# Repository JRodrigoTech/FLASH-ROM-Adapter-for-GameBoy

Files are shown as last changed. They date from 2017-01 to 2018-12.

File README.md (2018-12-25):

# SOP-32L FLASH to ROM Adapter for Game Boy Cartridges

Game-Boy-SOP-32-Flash-to-ROM-adapter-preview

---

# TSOP-44L FLASH to ROM Adapter

Game-Boy-TSOP-44-Flash-to-ROM-adapter-preview

#### NOTE : This adaptar this pretty hard to solder. If you are new in soldering, I recommend to use the SOP32 adapter because is much more easy to solder and fix.

---

## Compatible Flashes

AM29F016@-#E* (2 MB) or AM29F032@-#E* (4 MB)
```
 @ = Manufactured process technology (None = 0.5 µm, B = 0.32 µm, D = 0.23 µm)
 # = any speeds are compatible (75,90,120,150)
 E = 48-Pin Thin Small Outline Package (TSOP) Standard Pinout (TS 048)
 * = any temperature range (C = Commercial (0°C to +70°C) or I = Industrial (-40°C to +85°C))
```
*Ex: AM29F016-75EC, AM29F032B-120EI,...* 

---

## [How To - Assembly Guide](http://www.jrodrigo.net/wiki/how-to-diy-a-gameboy-flash-cartridge-with-a-rom-adapter-board/)

## Where to buy :package:
- [**Tindie** with optional presolded 2MB/4MB ROM](https://www.tindie.com/products/JRodrigo/flash-memory-adapter-for-some-game-boy-cartridges/)
- [**OSHpark** (SOP32 bare PCBs only)](https://oshpark.com/shared_projects/5S5OQRXm)
- [**OSHpark** (TSOP44 bare PCBs only)](https://oshpark.com/shared_projects/Ks4WbXlo)
- [**PCBWay** (SOP32 bare PCBs only)](https://www.pcbway.com/project/shareproject/Flash_Memory_Adapter_for_Game_Boy.html)

---

## License
#### Licenced under [Creative Commons - Attribution and Share Alike](https://github.com/JRodrigoTech/FLASH-ROM-Adapter-for-GameBoy/blob/master/LICENSE.md) by [J.Rodrigo](http://www.jrodrigo.net)

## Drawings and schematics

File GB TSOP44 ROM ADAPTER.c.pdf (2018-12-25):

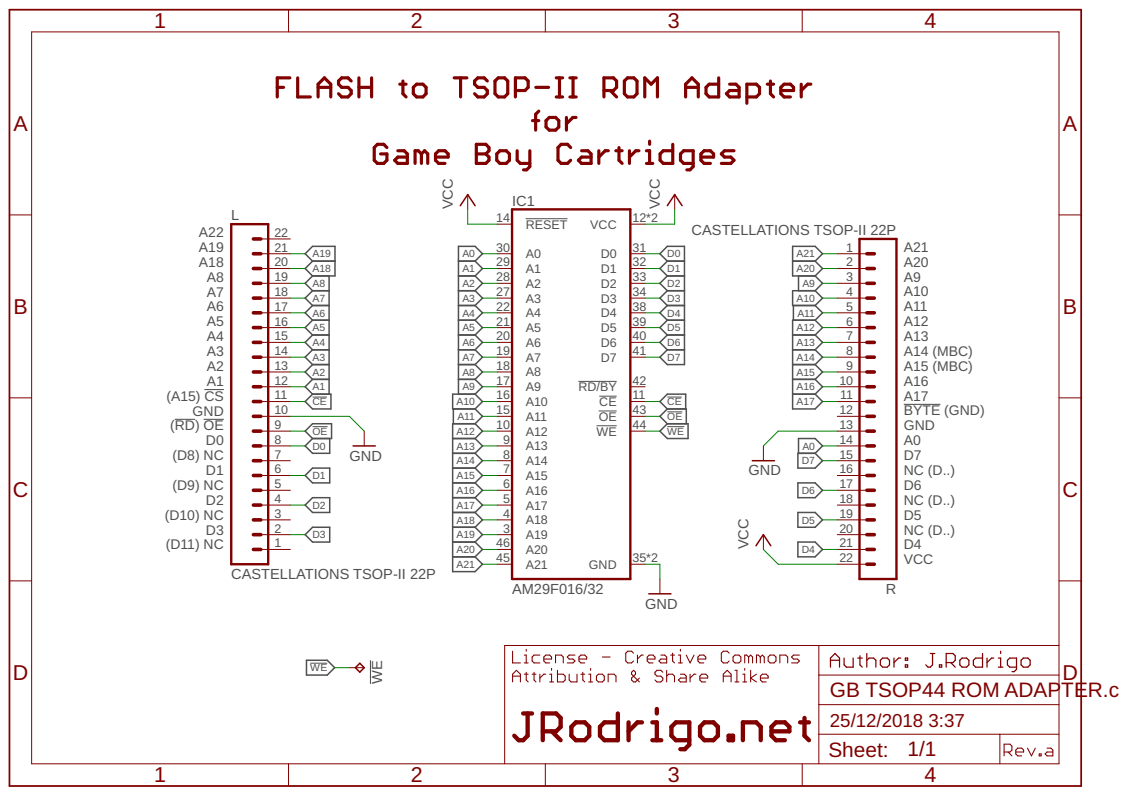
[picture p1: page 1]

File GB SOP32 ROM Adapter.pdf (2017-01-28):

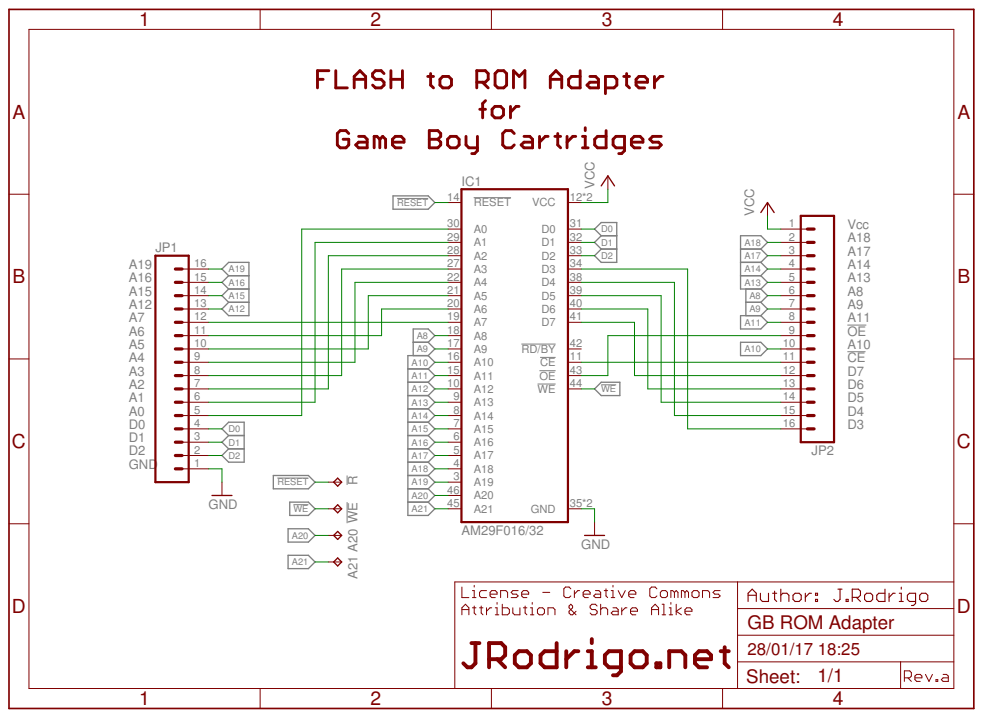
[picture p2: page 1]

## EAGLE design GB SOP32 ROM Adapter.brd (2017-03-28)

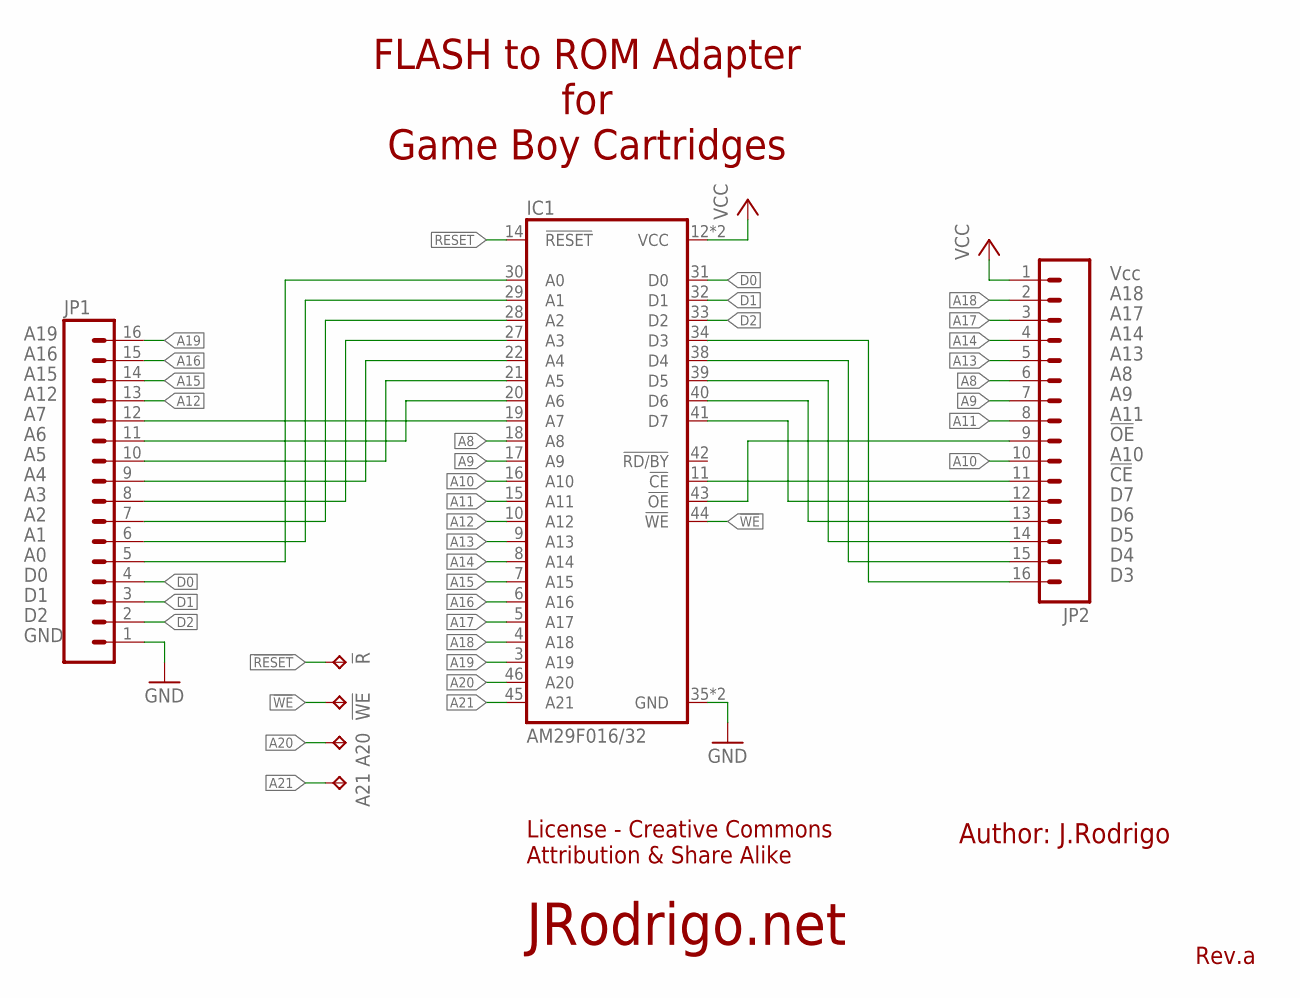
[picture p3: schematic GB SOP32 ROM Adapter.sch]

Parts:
!R: TPTP08SQ; TP08SQ
!WE: TPTP08SQ; TP08SQ
A20, A21: TPTP08SQ; TP08SQ
IC1: AM29F016/32; TSOP48
JP1, JP2: CASTELLATIONS_16-PINS*; CASTELLATIONS_16-PINS

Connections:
!RESET: !R.TP, IC1.14 (!RESET)
!WE: !WE.TP, IC1.44 (!WE)
A8: IC1.18 (A8), JP2.6
A9: IC1.17 (A9), JP2.7
A10: IC1.16 (A10), JP2.10
A11: IC1.15 (A11), JP2.8
A12: IC1.10 (A12), JP1.13
A13: IC1.9 (A13), JP2.5
A14: IC1.8 (A14), JP2.4
A15: IC1.7 (A15), JP1.14
A16: IC1.6 (A16), JP1.15
A17: IC1.5 (A17), JP2.3
A18: IC1.4 (A18), JP2.2
A19: IC1.3 (A19), JP1.16
A20: A20.TP, IC1.46 (A20)
A21: A21.TP, IC1.45 (A21)
D0: IC1.31 (D0), JP1.4
D1: IC1.32 (D1), JP1.3
D2: IC1.33 (D2), JP1.2
GND: IC1.35 (GND), IC1.36 (GND), JP1.1
unnamed: IC1.34 (D3), JP2.16
unnamed: IC1.38 (D4), JP2.15
unnamed: IC1.39 (D5), JP2.14
unnamed: IC1.40 (D6), JP2.13
unnamed: IC1.41 (D7), JP2.12
unnamed: IC1.11 (!CE), JP2.11
unnamed: IC1.43 (!OE), JP2.9
unnamed: IC1.29 (A1), JP1.6
unnamed: IC1.28 (A2), JP1.7
unnamed: IC1.30 (A0), JP1.5
unnamed: IC1.27 (A3), JP1.8
unnamed: IC1.22 (A4), JP1.9
unnamed: IC1.21 (A5), JP1.10
unnamed: IC1.20 (A6), JP1.11
unnamed: IC1.19 (A7), JP1.12
VCC: IC1.12 (VCC), IC1.37 (VCC), JP2.1

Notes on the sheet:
A19
A16
A15
A12
GND
Vcc
A18
A17
A14
A13
A11
!OE
A10
!CE
FLASH to ROM Adapter for Game Boy Cartridges
Rev.a
Author: J.Rodrigo
License - Creative Commons Attribution & Share Alike
JRodrigo.net

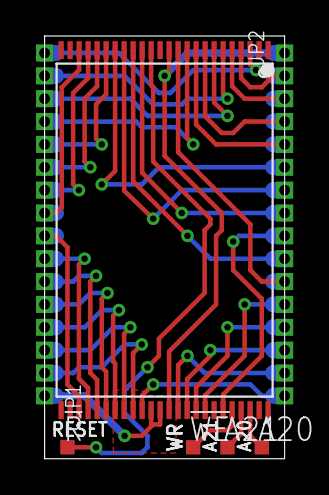
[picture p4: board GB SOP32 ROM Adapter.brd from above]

Board: 2 copper layers, 13.3 x 23.5 mm, 7 parts (0 on the bottom side), 36 nets.

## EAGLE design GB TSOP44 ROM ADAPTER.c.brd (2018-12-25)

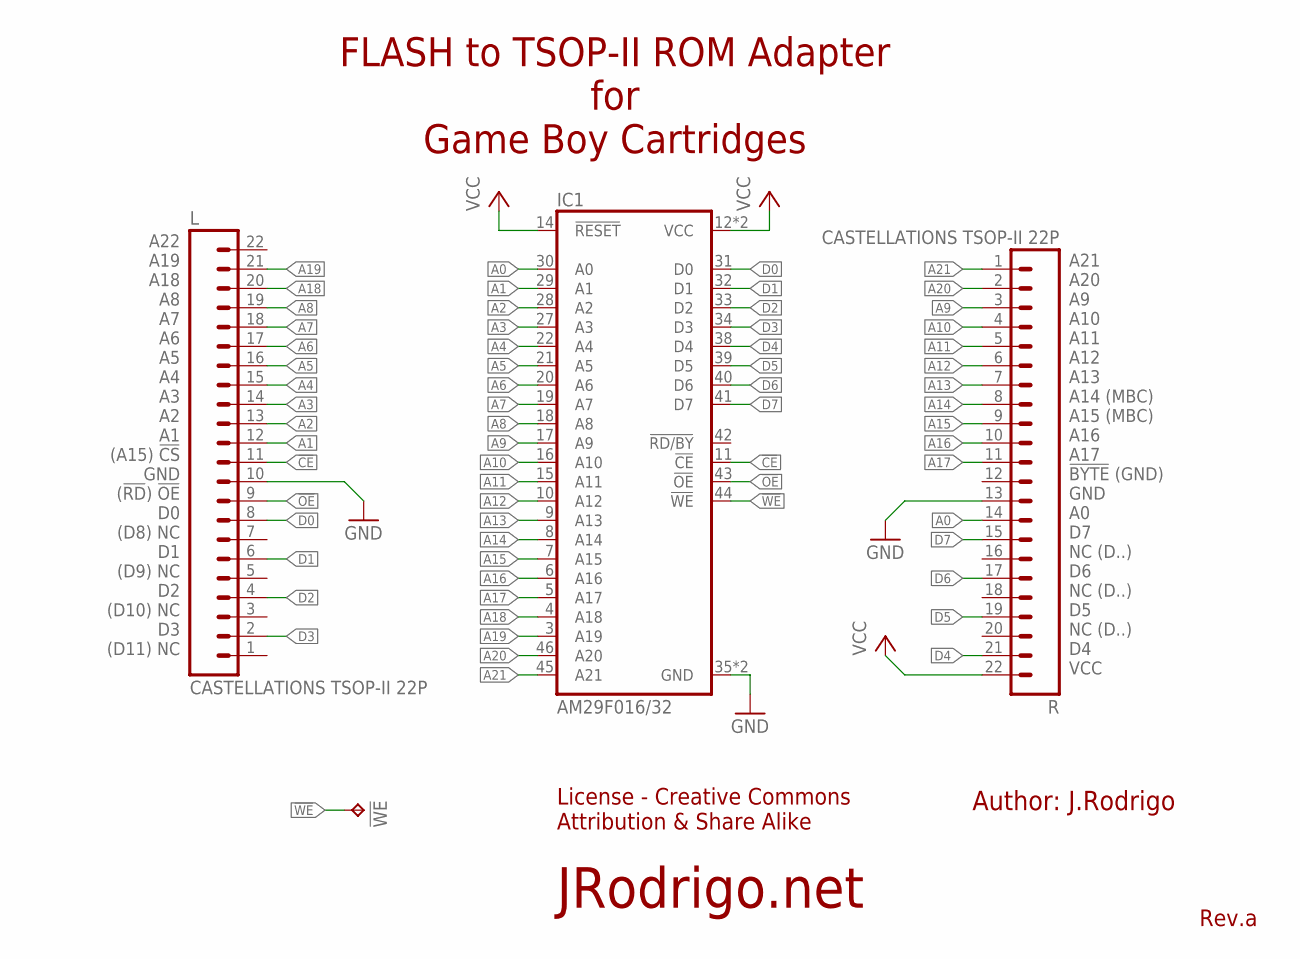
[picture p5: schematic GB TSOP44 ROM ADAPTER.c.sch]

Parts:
!WE: TPTP06SQ; TP06SQ
IC1: AM29F016/32; TSOP48-2
L: CASTELLATIONS TSOP-II 22P; CASTELLATIONS_TSOP_II_22PHH
R: CASTELLATIONS TSOP-II 22P; CASTELLATIONS_TSOP_II_22PHH

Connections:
!CE: IC1.11 (!CE), L.11
!OE: IC1.43 (!OE), L.9
!WE: !WE.TP, IC1.44 (!WE)
A0: IC1.30 (A0), R.14
A1: IC1.29 (A1), L.12
A2: IC1.28 (A2), L.13
A3: IC1.27 (A3), L.14
A4: IC1.22 (A4), L.15
A5: IC1.21 (A5), L.16
A6: IC1.20 (A6), L.17
A7: IC1.19 (A7), L.18
A8: IC1.18 (A8), L.19
A9: IC1.17 (A9), R.3
A10: IC1.16 (A10), R.4
A11: IC1.15 (A11), R.5
A12: IC1.10 (A12), R.6
A13: IC1.9 (A13), R.7
A14: IC1.8 (A14), R.8
A15: IC1.7 (A15), R.9
A16: IC1.6 (A16), R.10
A17: IC1.5 (A17), R.11
A18: IC1.4 (A18), L.20
A19: IC1.3 (A19), L.21
A20: IC1.46 (A20), R.2
A21: IC1.45 (A21), R.1
D0: IC1.31 (D0), L.8
D1: IC1.32 (D1), L.6
D2: IC1.33 (D2), L.4
D3: IC1.34 (D3), L.2
D4: IC1.38 (D4), R.21
D5: IC1.39 (D5), R.19
D6: IC1.40 (D6), R.17
D7: IC1.41 (D7), R.15
GND: IC1.35 (GND), IC1.36 (GND), L.10, R.13
VCC: IC1.12 (VCC), IC1.14 (!RESET), IC1.37 (VCC), R.22

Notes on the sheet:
FLASH to TSOP-II ROM Adapter for Game Boy Cartridges
Rev.a
Author: J.Rodrigo
License - Creative Commons Attribution & Share Alike
JRodrigo.net
A22 A19 A18 A8 A7 A6 A5 A4 A3 A2 A1 (A15) !CS! GND (!RD!) !OE! D0 (D8) NC D1 (D9) NC D2 (D10) NC D3 (D11) NC
A21 A20 A9 A10 A11 A12 A13 A14 (MBC) A15 (MBC) A16 A17 !BYTE! (GND) GND A0 D7 NC (D..) D6 NC (D..) D5 NC (D..) D4 VCC

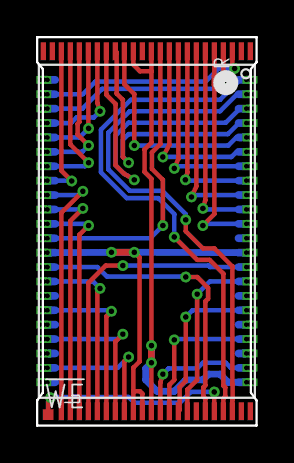
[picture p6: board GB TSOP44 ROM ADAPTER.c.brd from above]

Board: 2 copper layers, 12.2 x 21.6 mm, 4 parts (0 on the bottom side), 35 nets.

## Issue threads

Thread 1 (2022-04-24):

40 pin tsop

NO-ob, 2022-04-24:
Is it possible to use a 40 pin tsop? I ordered AM29F032B-90EI and its 40 pin

JRodrigoTech, 2022-04-26:
Yes, you need to solder it in the middle of the footprint leaving 2 pads unused on each side.

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

NO-ob, 2022-04-27:
Cool thankyou, turns out I ordered the wrong adapter anyway lol

Closed 2022-04-27.

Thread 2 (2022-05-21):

Unable to erase/flash

NO-ob, 2022-05-21:
Hi I made an mcb30 flashcart with your adapter I think ive gotten everything soldered correctly. I'm using a gbxcartrw and flashgbx and not able to flash a rom onto the cart. I asked for help in the inside gadgets discord they got me to check continuity on a bunch of points and everything seems to be soldered okay. I am able to dump the rom okay but it will not flash do you know what the issue could be?

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

ThalesMR, 2022-08-28:
Hi, I have being facing the same problem, I believe that you need to solder the wr wire as you did, but I believe you missed the wire for A20 pin on MBC3 chip. Anyway, I believe that we cannot erase the chip with Insidegedgets writer, so we probably need to buy the jrodrigo writer to be able to flash it.

ThalesMR, 2022-09-05:
I had to redo all solder joins to get it working, you need to make sure that the wire from pin3 to wr is well solder.

NO-ob, 2022-09-05:
Is that the wire to the pad on the corner? ill double check it

ThalesMR, 2022-09-05:
Yes, that wire, you need to check that wire solder

ThalesMR, 2022-09-05:
I had success after resolveriam that wire

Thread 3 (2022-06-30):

Wiring 44 adapter help

remy, 2022-06-30:
I bought the 32 pin version recently from your tindie account and realised it wouldn't fit the board I was going into, so ordered the 44 pin version from OSHpark as recommend by your github.

The problem I have is that the wiring (beyond soldering the adapter and flash chip) required - it's not really documented anywhere so I've found myself guessing a little.

The wiring I've added already is WR from the adapter to the /WR on the MBC5 chip.

I've also soldered MBC5 A20 to A20 on the flash chip (based on this pinout https://www.datasheetq.com/datasheet-download/16123/1/AMD/AM29F016B) - but I'm not sure if that's right as it wasn't specifically highlighted on the PCB.

I've not soldered the RESET pin from the flash chip - because as above, I wasn't sure.

Can you advise at all?

Thank you (also cc'd to your tindie account)

remy, 2022-07-06:
This is a photo of the wired board as it stands. I realised that originally I wrongly connected A20 off the flash IC, because I was using a 48 TSOP chip. Pins 45 onwards are: NC, A20, NC, NC - so I've bridged all those off to MBC5 A20.

The flash is still not detected, but I'm fairly sure the wiring is now correct as to what it expects.

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

atsidaev, 2023-08-14:
I've converted my Pokemon Crystal (MBC30) to flash cart yesterday using Javier's PCB design. The only required wire was the one to /WR pin. Despite the /RESET is connected to VCC in the adapter internally, it didn't caused any issues with flashing. Even autodetection in FlashGBX works as expected. Cannot say anything on address lines since my cart already had all of them connected to the original ROM.

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

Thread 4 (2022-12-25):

RESET Pin 14 on ROM to RESET or (not)RESET

KoopsF, 2022-12-25:
I've seen another flashcard project that connects the RESET pin on the ROM to the RESET pin on the board, not the (not)RESET.
Does anybody know why?

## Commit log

2017-01-28 Initial board release
    Some boards ordered to OSHpark, untested onboard.
    [GB ROM Adapter.brd, GB ROM Adapter.sch]
2017-02-20 Update of README.md
    Board are tested and fully working, coming soon on Tindie.
2017-03-28 Updated silk screen
    [GB ROM Adapter.brd]
2017-04-07 Update README.md
    Added the assembly guide and "where to buy", removed the "ToDo" section.
2018-12-25 First files version renamed to SOP44
    [GB SOP44 ROM Adapter.brd, GB SOP44 ROM Adapter.sch]
2018-12-25 New TSOP44 adapter files
    [GB TSOP44 ROM ADAPTER.c.brd, GB TSOP44 ROM ADAPTER.c.sch]
2018-12-25 First files version fixed renamed to SOP32 ✌️
    [GB SOP32 ROM Adapter.brd, GB SOP32 ROM Adapter.sch]
